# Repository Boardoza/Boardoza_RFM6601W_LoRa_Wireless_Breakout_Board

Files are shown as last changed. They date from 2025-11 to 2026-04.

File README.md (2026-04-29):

# Boardoza RFM6601W LoRa Wireless Communication Module Breakout Board

The **Boardoza RFM6601W** is a LoRa wireless communication module designed by **HOPERF**, featuring an integrated LoRa transceiver, RF transmitter/receiver, and a powerful **32-bit ARM Cortex-M4 RISC microcontroller** operating at 48 MHz. This module is ideal for long-range, low-power wireless applications including IoT sensor networks, smart agriculture, industrial monitoring, and remote telemetry systems.

The module operates with **3.3V or 5V** supply voltage and communicates via **UART** interface, making it compatible with a wide range of microcontroller platforms. It supports operating frequencies  **868 MHz** with exceptional receiving sensitivity of **-138 dBm** at maximum spreading factor.

## [Click here to purchase!](https://www.ozdisan.com/p/arduino-sensorleri-ve-modulleri-613/boardoza-boardoza-rfm6601w-1202716)

|Front Side|Back Side|
|:---:|:---:|
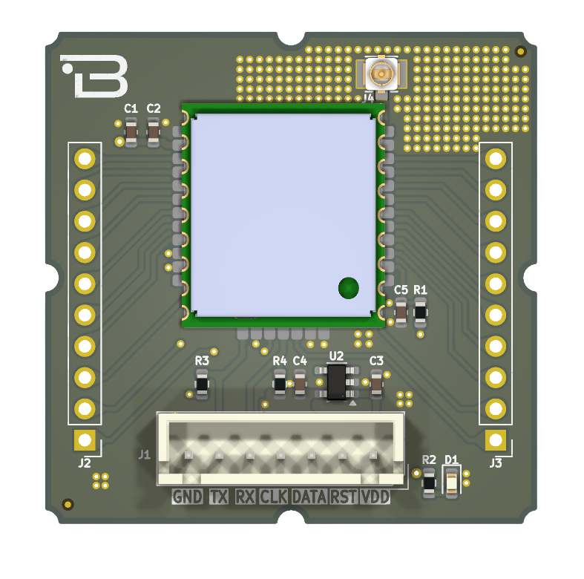
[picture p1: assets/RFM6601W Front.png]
RFM6601W Front
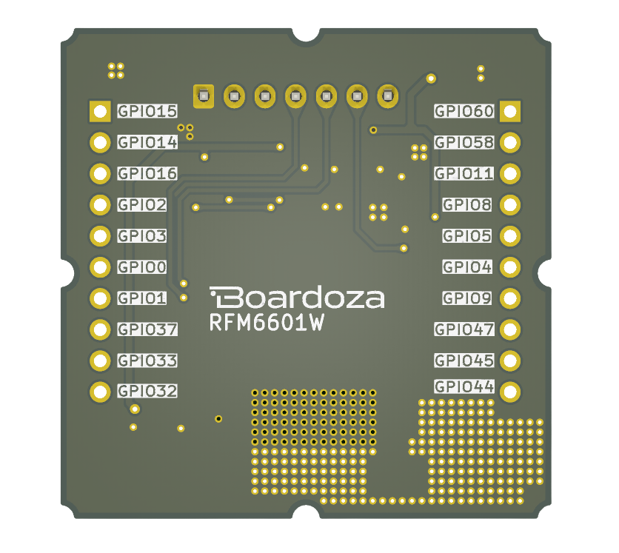
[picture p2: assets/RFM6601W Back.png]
RFM6601W Back
| | |

---

## Key Features

- **Integrated MCU:** 32-bit ARM Cortex-M4 processor at 48 MHz.  
- **Operation Frequency Range:** 868 MHz ISM bands.
- **High Sensitivity:** –138 dBm at SF=12, BW=125 kHz.  
- **Adjustable Output Power:** Up to +2 dBm.  
- **Low Power Consumption:** 10 mA RX, 20 mA TX at +2 dBm.  
- **Simple UART Interface:** Easy integration with most microcontrollers.  
- **Dual Voltage Support:** Operates at 3.3V or 5V.  
- **Compact Form Factor:** Ideal for wireless embedded applications.  

---

## Technical Specifications

**Manufacturer:** HOPERF  
**Model:** RFM6601W  
**Input Voltage:** 3.3V - 5V  
**Voltage Input Type:** 7-pin 2.50mm header  
**Interface:** UART  
**Functions:** LoRa Wireless Communication Module  
**Processor:** ARM Cortex-M4 32-bit RISC MCU  
**Clock Speed:** 48 MHz  
**Frequency Range:** 868 MHz - 868.2 MHz (continuous coverage)  
**Operating Frequencies:**  868 MHz  
**Receiving Sensitivity:** -138 dBm @SF=12, BW=125KHz  
**Transmit Current:** 20 mA @+2dBm, 868MHz  
**Receive Current:** 10 mA @868.1MHz  
**Operating Temperature:** -40°C ~ +85°C  
**Board Dimensions:** 40mm x 40mm

---

## Board Pinout

### **( J1 ) Main Communication & Power Pins**

| Pin Number | Pin Name | Description |
|:---:|:---:|---|
| 1 | GND | Ground |
| 2 | TX | MCU GPIO (UART_RXD) |
| 3 | RX | MCU GPIO (UART_TXD) |
| 4 | CLOCK | SWD CLK (Serial Wire Debug Clock) |
| 5 | DATA | SWD DATA (Serial Wire Debug Data) |
| 6 | RESET | Reset signal (active low) |
| 7 | VDD | Power supply input (3.3V - 5V) |

### **( J2 ) GPIO Extension Pins**

| Pin Number | Pin Name | Description |
|:---:|:---:|---|
| 1 | GPIO32 | MCU General Purpose I/O |
| 2 | GPIO33 | MCU General Purpose I/O |
| 3 | GPIO37 | MCU General Purpose I/O |
| 4 | GPIO1 | MCU General Purpose I/O |
| 5 | GPIO0 | MCU General Purpose I/O |
| 6 | GPIO03 | MCU General Purpose I/O |
| 7 | GPIO02 | MCU General Purpose I/O |
| 8 | GPIO16 | MCU General Purpose I/O |
| 9 | GPIO14 | MCU General Purpose I/O |
| 10 | GPIO15 | MCU General Purpose I/O |

### **( J3 ) GPIO Extension Pins**

| Pin Number | Pin Name | Description |
|:---:|:---:|---|
| 1 | GPIO44 | MCU General Purpose I/O |
| 2 | GPIO45 | MCU General Purpose I/O |
| 3 | GPIO47 | MCU General Purpose I/O |
| 4 | GPIO09 | MCU General Purpose I/O |
| 5 | GPIO04 | MCU General Purpose I/O |
| 6 | GPIO05 | MCU General Purpose I/O |
| 7 | GPIO08 | MCU General Purpose I/O |
| 8 | GPIO11 | MCU General Purpose I/O |
| 9 | GPIO58 | MCU General Purpose I/O |
| 10 | GPIO60 | MCU General Purpose I/O |

---

## Board Dimensions

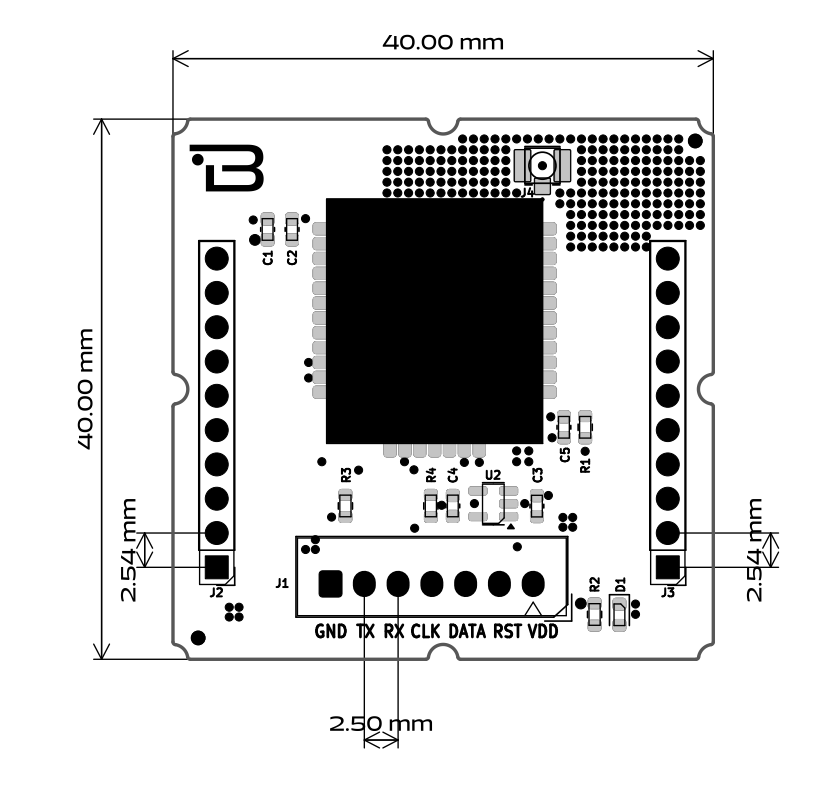
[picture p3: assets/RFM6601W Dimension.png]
RFM6601W Dimensions


---

## Compatible Antennas

For reliable and long-range RF performance in the **868 MHz ISM band**, it is strongly recommended to use a properly tuned **50Ω external antenna** specifically designed for 868 MHz operation. A matched antenna improves transmission efficiency, enhances receiver sensitivity, and ensures stable communication performance.

Using an antenna optimized for the operating frequency helps minimize return loss, low VSWR (Voltage Standing Wave Ratio) and maximizes RF power transfer from the module.

[Recommended Antenna: 868 MHz 3 dBi Omni-Directional LoRa SMA Antenna](https://www.ozdisan.com/p/rf-antenler-660/sunnyway-rf-swf022-sw24008ib77-1210812)

**Key Antenna Characteristics:**

- **Frequency:** 868 MHz ISM Band  
- **Gain:** 3.62 dBi  
- **Radiation Pattern:** Omni-directional  
- **Connector Type:** IPEX MHF1  
- **Impedance:** 50Ω  

>  **Important:** Always connect the antenna before powering the RF module. Operating the module without a connected antenna may cause RF stage damage and significantly reduce transmission performance.

---

## Step Files

[Boardoza RFM6601W.step](./assets/RFM6601W%20Step.step)

---

## Datasheet

[HOPERF RFM6601W Datasheet.pdf](./assets/RFM6601W%20Datasheet.pdf)

---

## Version History

- V1.0.0 - Initial Release

---

## Support

- If you have any questions or need support, please contact <support@boardoza.com>

---

## License

Shield: [][cc-by-sa]

This work is licensed under a [Creative Commons Attribution-ShareAlike 4.0 International License][cc-by-sa].

[][cc-by-sa]

[cc-by-sa]: http://creativecommons.org/licenses/by-sa/4.0/
[cc-by-sa-image]: https://licensebuttons.net/l/by-sa/4.0/88x31.png
[cc-by-sa-shield]: https://img.shields.io/badge/License-CC%20BY--SA%204.0-lightgrey.svg

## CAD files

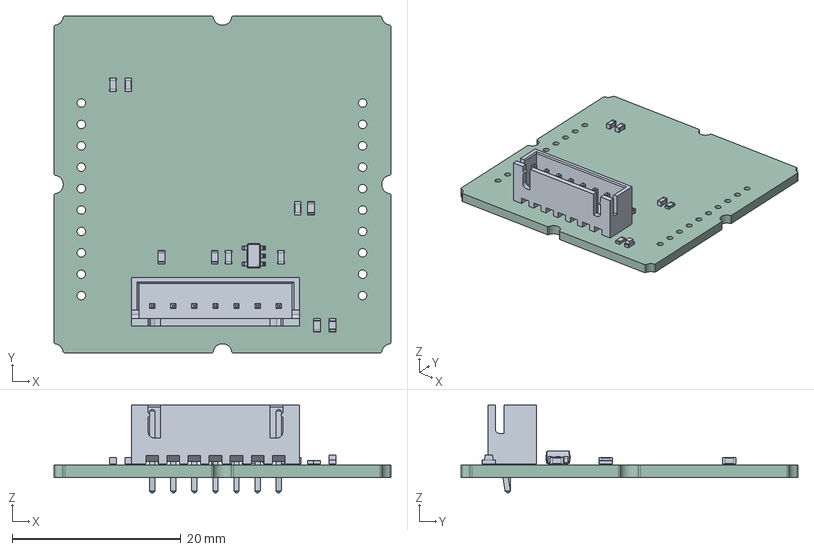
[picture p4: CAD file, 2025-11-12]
assets/RFM6601W Step.step
40.0 x 40.0 x 10.4 mm
C_0603_1608Metric x 5
LED_0603_1608Metric
SOT-23-5
R_0603_1608Metric x 4
JST_XH_B7B-XH-A_1x07_P2.50mm_Vertical
kibot_e6mrep0n_PCB

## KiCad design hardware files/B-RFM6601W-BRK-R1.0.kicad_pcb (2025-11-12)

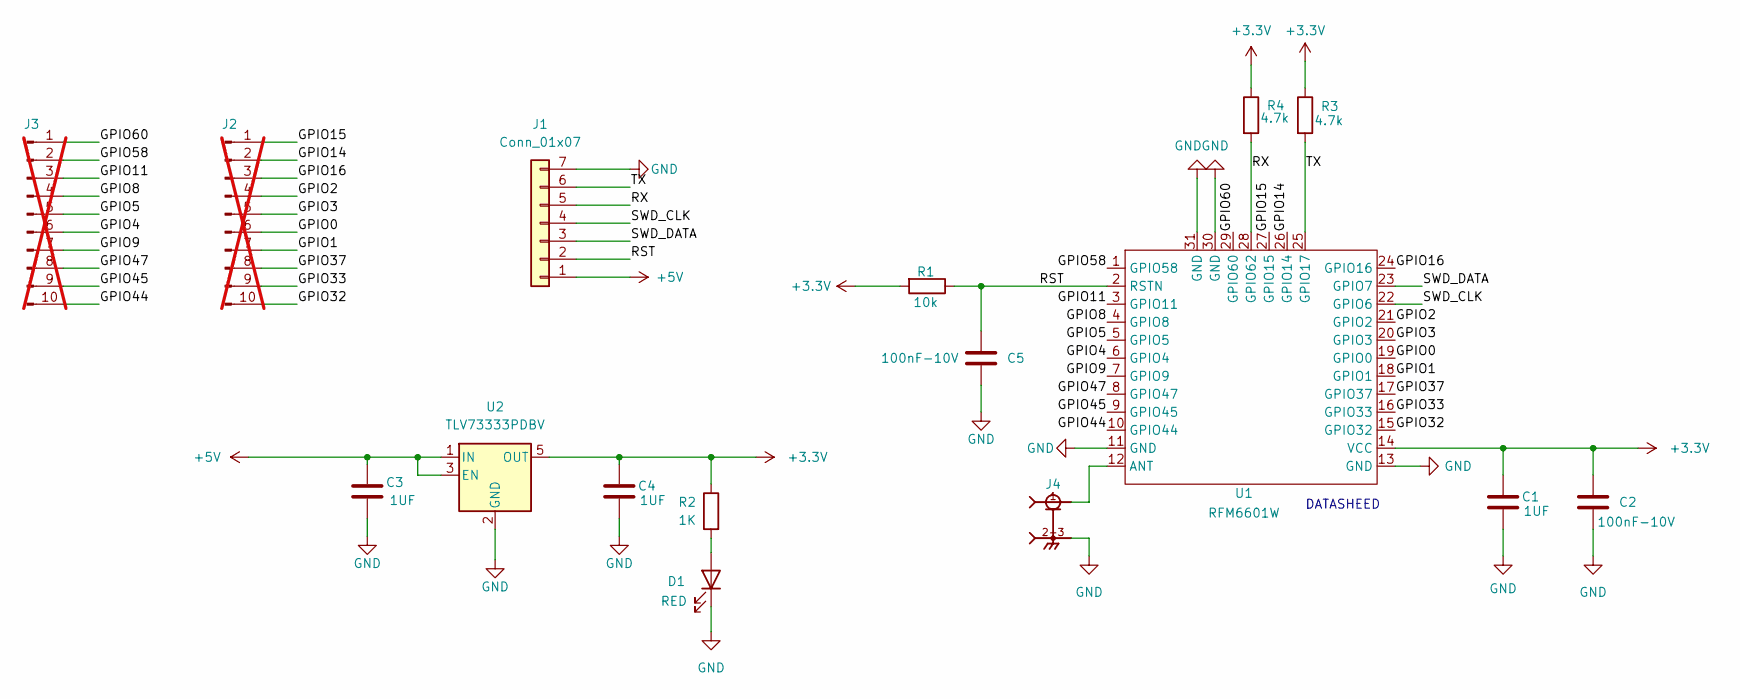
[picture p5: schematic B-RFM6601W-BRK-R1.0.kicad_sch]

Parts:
C1, C3, C4: 1UF; C_0603_1608Metric; MPN CL10A105KO8NNNC
C2, C5: 100nF-10V; C_0603_1608Metric; MPN CL10B104KO8NNNC
D1: RED; LED_0603_1608Metric; MPN LTST-C190KRKT
J1: Conn_01x07; 2317-07S_1x07_P2.50mm_Vertical; MPN L-KLS1-2.50-07-S
J2, J3: Conn_01x10_Pin; PinHeader_1x10_P2.54mm_Vertical; not fitted
J4: U.FL-R-SMT_10_; HRS_U.FL-R-SMT_10_; MPN L-KLS1-IPEX-20279-001E-0
R1: 10k; R_0603_1608Metric; MPN RC0603JR-0710KL
R2: 1K; R_0603_1608Metric; MPN RC0603JR-071KL
R3, R4: 4.7k; R_0603_1608Metric; MPN 2.485.430
U1: RFM6601W; MPN RFM6601W-868S2
U2: TLV73333PDBV; SOT-23-5; MPN TLV73333PDBVR

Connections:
+3.3V: C1.1, C2.1, C4.1, R1.2, R2.1, R3.1, R4.1, U1.14 (VCC), U2.5 (OUT)
+5V: C3.1, J1.1, U2.1 (IN), U2.3 (EN)
/GPIO0: J2.6, U1.19 (GPIO0)
/GPIO1: J2.7, U1.18 (GPIO1)
/GPIO2: J2.4, U1.21 (GPIO2)
/GPIO3: J2.5, U1.20 (GPIO3)
/GPIO4: J3.6, U1.6 (GPIO4)
/GPIO5: J3.5, U1.5 (GPIO5)
/GPIO8: J3.4, U1.4 (GPIO8)
/GPIO9: J3.7, U1.7 (GPIO9)
/GPIO11: J3.3, U1.3 (GPIO11)
/GPIO14: J2.2, U1.26 (GPIO14)
/GPIO15: J2.1, U1.27 (GPIO15)
/GPIO16: J2.3, U1.24 (GPIO16)
/GPIO32: J2.10, U1.15 (GPIO32)
/GPIO33: J2.9, U1.16 (GPIO33)
/GPIO37: J2.8, U1.17 (GPIO37)
/GPIO44: J3.10, U1.10 (GPIO44)
/GPIO45: J3.9, U1.9 (GPIO45)
/GPIO47: J3.8, U1.8 (GPIO47)
/GPIO58: J3.2, U1.1 (GPIO58)
/GPIO60: J3.1, U1.29 (GPIO60)
/RST: C5.1, J1.2, R1.1, U1.2 (RSTN)
/RX: J1.5, R4.2, U1.28 (GPIO62)
/SWD_CLK: J1.4, U1.22 (GPIO6)
/SWD_DATA: J1.3, U1.23 (GPIO7)
/TX: J1.6, R3.2, U1.25 (GPIO17)
GND: C1.2, C2.2, C3.2, C4.2, C5.2, D1.1 (K), J1.7, J4., J4.2, J4.2-3, J4.3, U1.11 (GND), U1.13 (GND), U1.30 (GND), U1.31 (GND), U2.2 (GND)
unnamed: D1.2 (A), R2.2
unnamed: J4.1, U1.12 (ANT)

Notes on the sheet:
DATASHEED

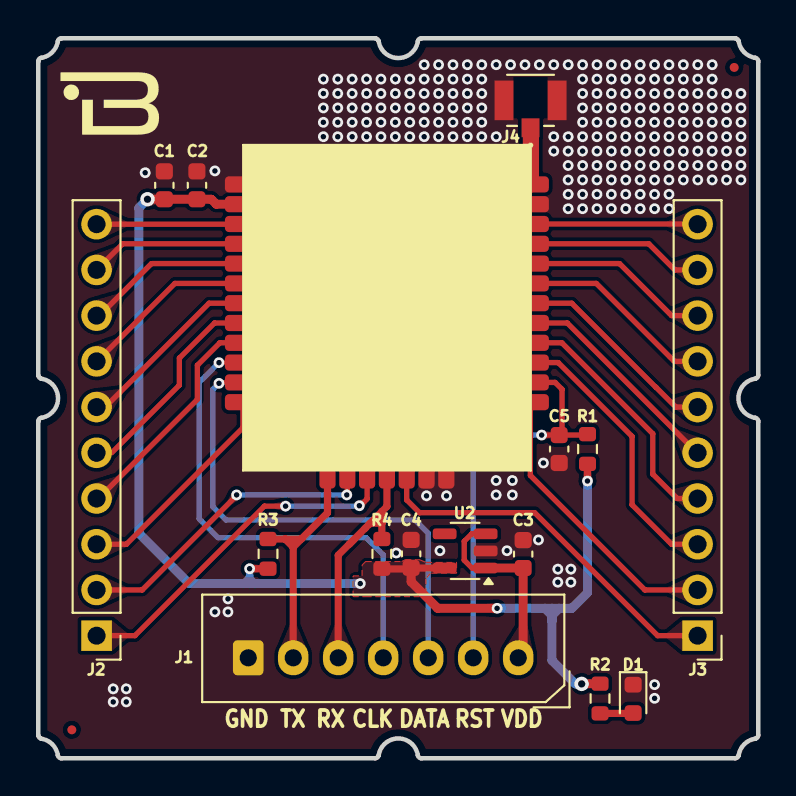
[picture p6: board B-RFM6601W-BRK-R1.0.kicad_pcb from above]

Board: 2 copper layers, 40.0 x 40.0 mm, 16 parts (0 on the bottom side), 30 nets.

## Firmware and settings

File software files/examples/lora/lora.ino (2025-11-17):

#include <Arduino.h>

#define LORARESET 8
#define LED_PIN   7
#define BUTTON_PIN 6

volatile uint8_t ok_bit = 0, join_bit = 0, sent_bit = 0, RECV = 0, BUTON1 = 0;
char CDEVEUI[] = "AT+CDEVEUI=70B3D57ED0068400\r\n";
char CAPPEUI[] = "AT+CAPPEUI=D896E0E000005204\r\n";
char CAPPKEY[] = "AT+CAPPKEY=95938CCB69D0D17FDD7BA2FFE0FB8452\r\n";
char CCLASS[] = "AT+CCLASS=2\r\n";
char CJOIN[] = "AT+CJOIN=1,0,8,8\r\n";
char DTRX[] = "AT+DTRX=1,2,3,112233\r\n";
char DTRXB[] = "AT+DTRX=1,2,1,EE\r\n";

uint8_t receive_array[128], receive_data[128];
uint8_t bitcounter = 0;

void UART0_IRQHandler() {
    while (Serial.available()) {
        char receive_byte = Serial.read();
        if (receive_byte == '\n' && receive_array[bitcounter - 1] == '\r') {
            if (strstr((const char*)receive_array, "OK")) ok_bit = 1;
            if (strstr((const char*)receive_array, "+CJOIN:OK")) join_bit = 1;
            if (strstr((const char*)receive_array, "+CJOIN:FAIL")) join_bit = 2;
            if (strstr((const char*)receive_array, "OK+SENT:01")) sent_bit = 1;
            if (strstr((const char*)receive_array, "OK+RECV:00,02")) {
                RECV = 1;
                memcpy(receive_data, receive_array, 128);
            }
            memset(receive_array, 0, 128);
            bitcounter = 0;
        } else {
            receive_array[bitcounter++] = receive_byte;
        }
    }
}

void setup() {
    Serial.begin(9600);
    pinMode(LORARESET, OUTPUT);
    pinMode(LED_PIN, OUTPUT);
    pinMode(BUTTON_PIN, INPUT_PULLUP);
    
    attachInterrupt(digitalPinToInterrupt(BUTTON_PIN), [] { BUTON1 = 1; }, FALLING);
    
    digitalWrite(LORARESET, LOW);
    delay(100);
    digitalWrite(LORARESET, HIGH);
    delay(100);

    LORA_init();
}

void LORA_init() {
    Serial.print(CDEVEUI);
    while (!ok_bit);
    ok_bit = 0;

    Serial.print(CAPPEUI);
    while (!ok_bit);
    ok_bit = 0;

    Serial.print(CAPPKEY);
    while (!ok_bit);
    ok_bit = 0;

    Serial.print(CCLASS);
    while (!ok_bit);
    ok_bit = 0;

    Serial.print(CJOIN);
    while (join_bit == 0 || join_bit == 2) {
        if (join_bit == 2) {
            join_bit = 0;
            Serial.print(CJOIN);
        }
    }
    join_bit = 0;

    delay(1000);
    Serial.print(DTRX);
    while (!sent_bit);
    sent_bit = 0;
    ok_bit = 0;
    RECV = 0;
}

void loop() {
    if (RECV) {
        if (receive_data[17] == '1' && receive_data[18] == '1') {
            digitalWrite(LED_PIN, HIGH);
        }
        if (receive_data[17] == '2' && receive_data[18] == '2') {
            digitalWrite(LED_PIN, LOW);
        }
        RECV = 0;
    } else if (BUTON1) {
        BUTON1 = 0;
        Serial.print(DTRXB);
        while (!sent_bit);
        sent_bit = 0;
        ok_bit = 0;
        RECV = 0;
    }
}
